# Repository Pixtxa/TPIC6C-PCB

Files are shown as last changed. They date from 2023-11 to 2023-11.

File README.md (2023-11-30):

# TPIC6C-PCB

Breakout board for [TPIC6C596 shift registers with 8x open drain output](https://www.ti.com/product/TPIC6C596) with neopixels as status leds.

Rainbow animation Animation with outputs active
Single PCBs

## Features
* Daisy chaining of multiple boards
  * [nyanyanyanyanyanyanya](https://knowyourmeme.com/memes/nyanyanyanyanyanyanya)
  * "ONE WAY" marks represent the direction, where data goes in and where it comes out
* Neopixel LEDs (WS2812, WS2812B, SK6812 or whatever) 
  * Not needed, but nice to have
  * Work independent from the shift registers; only share the same voltage
  * Can be used as output status leds (2x RGBW = 8 bit) or whatever the software wants them to do
  * Can function as signal repeaters to connect a [NeoPixel Arcade Button](https://www.thingiverse.com/thing:823588) at the end
  * Even if your project is unfinished, it can have nice rainbow animations in an early state
* Main part
  * IC + Basic components
  * 1 Neopixel LED
  * GND, V+ and all 8 Outputs as 2.54 mm pitch THT connector
  * V+ and 5 Outputs (D0 ... D4) as 1.27 mm pitch SMD connector
  * 23 mm x 40.64 mm
  * Connection-Pitch of 35.56 mm
* Extension part
  * Can be cut away if not needed 
  * 1 Neopixel LED
    * Or solder jumper for connecting the data line without neopixel
  * GND, V+ and 4 Outputs as 2.54 mm pitch THT connector
  * V+ and 4 Outputs (D4 ... D7) as 1.27 mm pitch SMD connector
  * 2.54 mm screw connector for V+
  * Montage hole
  * Extends PCB to 23 mm x 85.08 mm
  * Connection-Pitch of 80 mm
  * Output connectors 40 mm appart of the main part ones, resulting in output pitch of 40 mm when using D0-D3 on main and D4-D7 on extension part
* Side Connectors
  * Double row connectors
    * Better stability
    * Box headers can be used to connect PCBs over longer distance
    * Can be used to variate the pitch a little
    * Half of outer holes can be cut away to have some kind of plated edge connector, but it doesn't really work for a huge amount of PCBs
  * SPI can be used to set the outputs
    * CLK: SCK
    * D_IN: MOSI
    * SS: Latch
  * Pinout
    * nCLEAR/nCLR (optional)
      * LOW = Reset IC
      * R1 as Pull-Up avialable
    * nOE/nG (optional)
      * LOW = Output Enable
      * R2 as Pull-Down avialable
      * Can be used for PWM dimming 
    * Latch/RSCK/SPI_SS
      * Rising Edge: Copy data from shift register to output registers
      * SPI_SS can be used
    * D_IN/SER_IN/SPI_MOSI
      * Data in
      * SPI_MOSI can be used
    * D_OUT/SER_OUT
      * Data out for next shift registers data in
    * CLK/RCK/SPI_SCK
      * Rising Edge: Move data one step forward
      * SPI_SCK can be used
    * 5V/VCC
      * 4.5 ... 5.5 V supply voltage for shift register logic and neopixel
      * Level shifters might be needed for the other input signals
    * GND
      * Ground
    * V+ (optional)
      * 0...33 V
      * Screw terminal can be used for individual V+ on each PCB
      * It's only passed, so it also can be wired external without connecting it to the PCB
    * LED_IN
      * Neopixel Data in
    * LED_OUT
      * Neopixel Data out
* Designed to control (huge amounts of) [WERMA](https://werma.com) signal lamps
  * 24V compatible outputs
  * V+ is X0/COM
  * D0-D7 are outputs for X1, X2, ...
  * GND can be used as always-on output (e. g. for powering a [24V eSIGN](https://www.werma.com/en/s_c1684i7007/65760055.html) or [Transceiver](https://www.werma.com/en/s_c0i6509/86200003.html))
  * Main part SMD connector features 5 Outputs, because KombiSIGN can handle up to 5 Tiers
  * 40 mm output pitch when using up to 4 outputs, because MC35 has 35 mm diameter and 4 inputs, leaving 5 mm space between lamps
  * 80 mm output pitch when using 5 or more outputs, because eSIGN/KS71/KS72 have 70 mm diameter, leaving 10 mm space between lamps



## Known bugs
* Heat transfer
  * Datasheet shows a recommended layout example which isn't in use
  * No problem for me, because I'm far away of these limits
  * Maybe gluing on heatsinks might work
  * Redesign options
    * Implement it
      * Using 4 Layers
      * Increase PCB size
    * Use another IC with better cooling options
    * Add dedicated MOSFETs for higher currents
* Voltage drop on power lines can cause problems on longer chains
  * Voltage drop on V+ only affects the outputs
  * Voltage drop on 5V mostly occurs when using the neopixels on high brightness
  * Voltage drop on GND affects the neopixels and shift registers and is mostly caused by enabled outputs
    * The shift registers glitch if voltage is too low
  * I've ordered the PCBs with only 1 oz Outer Copper Weight
  * I reccomend adding an extra cable for 5V, GND and V+ and connect it regulary
  * Redesign options
    * Add ground plane
    * Increase size of power lines, maybe use both sides of PCB, maybe also increase PCB size to fit everything
    * Order 2 oz Outer Copper Weight
    * Use 4 Layers
    * Pads for connecting cables that run in parallel
    * Use a single box connector for each PCB
      * Most current goes through external ribbon cable
      * Multiple wires for same power lines for less resistance
      * Somehow find an easy way to cut and connect the D_IN/D_OUT and LED_IN/LED_OUT wire correctly
* Missing Resistors/Power-On-Reset
  * Most MCUs have IOs that are inputs on startup and when uploading firmware
  * Open inputs act as antennas
  * Glitches are painful when the outputs are connected to loud buzzers
  * Adding an Pull-Up + IO to nOE helps
  * Redesign options
    * Adding option for Pull-Up on nOE, so outputs are off until the MCU switches this pin to LOW
      * Might cause problems if MCU doesn't run on 5 V and no level shifter is used
      * MCU would need this IO only for start up, if PWM-dimming isn't in use
        * Maybe add solder jumper to latch input; in some cases it's okay to blank all outputs when switching them
    * Adding a simple RC Power-On-Reset to nCLEAR and a Pull-Down to Latch
      * Data in the shift register might glitch, but the controller can fill it with data before latching it to the outputs
      * On power-on, the output registers would be cleared and stay off
      * On firmware upgrades/MCU-reset, the output registers will keep their value
        * Might result in an active buzzer
        * Allows silent/invisible MCU restarts/updates in the background
* Not all WERMA products can operate with V+ as COM
  * I've only had this problem with [LED Perm. Beacon WM 24VDC GN/YE/RD](https://www.werma.com/en/s_c1031i1973/89408055.html)
  * At least this board can drive PNP Transistors + Resistors as HIGH-Side-Switches
  * Redesign options
    * Add pads to V+ to add Pull-Up resistors, so P-Channel-MOSFETs can be used as HIGH-Side switches
      * These resistors could also help if LEDs light up dim because of EMC influences on long lines
      * These pads could also function for adding freewheeling diodes when switching inductive loads

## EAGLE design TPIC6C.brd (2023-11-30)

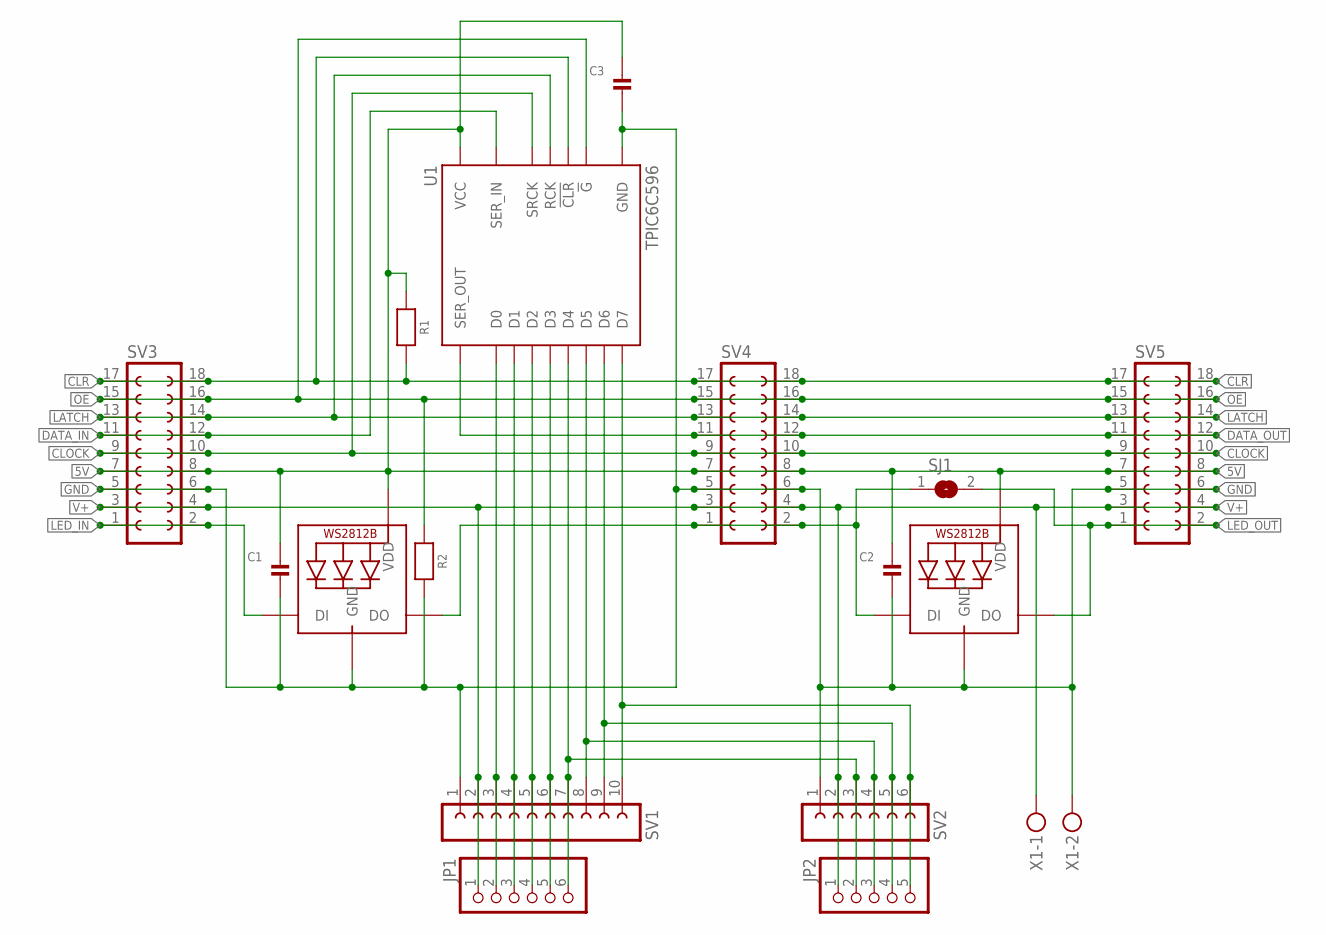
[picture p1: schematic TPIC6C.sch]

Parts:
C1, C2, C3: CAP_CERAMIC0603; 0603
JP1: HEADER-1X61X06_1.27MM; 1X06_1.27MM
JP2: HEADER-1X51.27MM; 1X05_1.27MM
LED1, LED2: WS2812B5050; WS2812B
R1, R2: MICROBUILDER_RESISTOR_0603_NOOUT; MICROBUILDER_0603-NO
SJ1: SOLDERJUMPER; SOLDERJUMPER_ARROW_NOPASTE
SV1: FE10-1; FE10
SV2: FE06-1; FE06
SV3, SV4, SV5: FE09-2NOSILK; FE09-2_NOSILK
U1: TPIC6C596; SO16
X1: MKDSN1,5/2-5,08

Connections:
5V: C1.1, C2.1, C3.1, LED1.1-VDD (VDD), LED2.1-VDD (VDD), R1.1, SV3.7, SV3.8, SV4.7, SV4.8, SV5.7, SV5.8, U1.1 (VCC)
!CLR: R1.2, SV3.17, SV3.18, SV4.17, SV4.18, SV5.17, SV5.18, U1.7 (!CLR)
!OE: R2.1, SV3.15, SV3.16, SV4.15, SV4.16, SV5.15, SV5.16, U1.8 (!G)
CLOCK: SV3.9, SV3.10, SV4.9, SV4.10, SV5.9, SV5.10, U1.15 (SRCK)
D0: JP1.2, SV1.3, U1.3 (D0)
D1: JP1.3, SV1.4, U1.4 (D1)
D2: JP1.4, SV1.5, U1.5 (D2)
D3: JP1.5, SV1.6, U1.6 (D3)
D4: JP1.6, JP2.2, SV1.7, SV2.3, U1.11 (D4)
D5: JP2.3, SV1.8, SV2.4, U1.12 (D5)
D6: JP2.4, SV1.9, SV2.5, U1.13 (D6)
D7: JP2.5, SV1.10, SV2.6, U1.14 (D7)
DATA_IN: SV3.11, SV3.12, U1.2 (SER_IN)
DATA_OUT: SV4.11, SV4.12, SV5.11, SV5.12, U1.9 (SER_OUT)
GND: C1.2, C2.2, C3.2, LED1.3-GND (GND), LED2.3-GND (GND), R2.2, SV1.1, SV2.1, SV3.5, SV3.6, SV4.5, SV4.6, SV5.5, SV5.6, U1.16 (GND), X1.2
LATCH: SV3.13, SV3.14, SV4.13, SV4.14, SV5.13, SV5.14, U1.10 (RCK)
LED_IN: LED1.4-DIN (DI), SV3.1, SV3.2
LED_OUT: LED2.2-DOUT (DO), SJ1.2, SV5.1, SV5.2
LED_OUT_IN: LED1.2-DOUT (DO), LED2.4-DIN (DI), SJ1.1, SV4.1, SV4.2
V+: JP1.1, JP2.1, SV1.2, SV2.2, SV3.3, SV3.4, SV4.3, SV4.4, SV5.3, SV5.4, X1.1

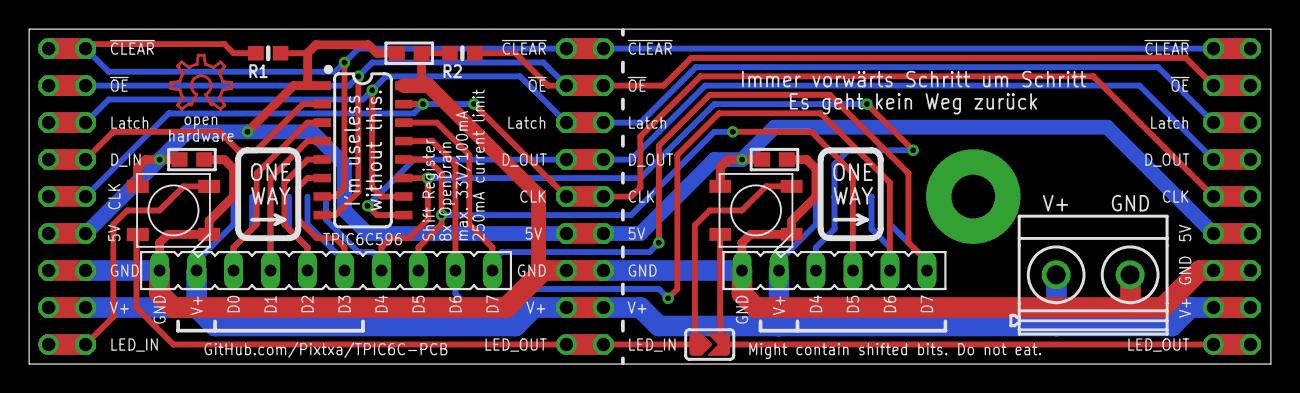
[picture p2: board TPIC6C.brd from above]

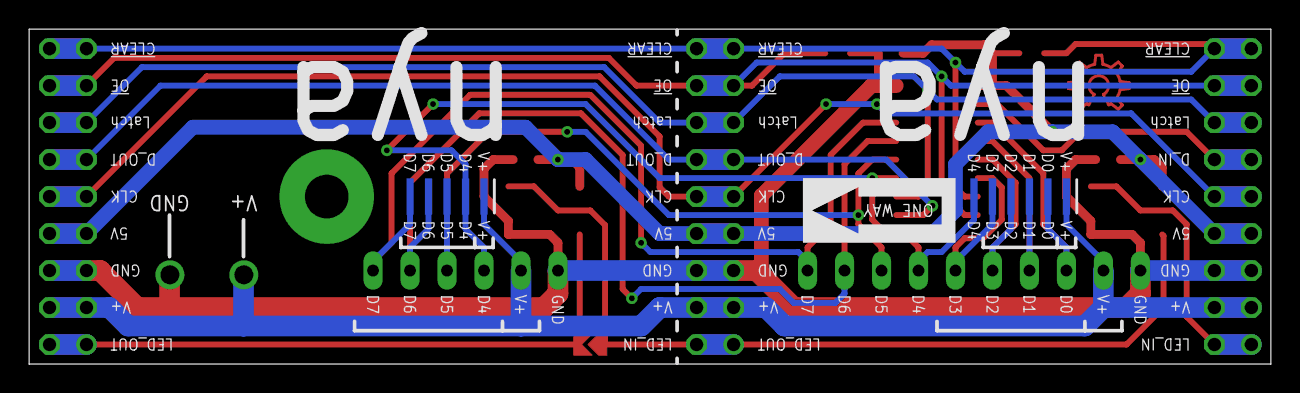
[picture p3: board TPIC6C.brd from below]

Board: 2 copper layers, 85.3 x 23.0 mm, 17 parts (2 on the bottom side), 20 nets.

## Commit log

2023-11-30 Added PCB design files
    [TPIC6C.brd, TPIC6C.sch]
2023-11-30 Update README.md
    Added detail picture of PCB

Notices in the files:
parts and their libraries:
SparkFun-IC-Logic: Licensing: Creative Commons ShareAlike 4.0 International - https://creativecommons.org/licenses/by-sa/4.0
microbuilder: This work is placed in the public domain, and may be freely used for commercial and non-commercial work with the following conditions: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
